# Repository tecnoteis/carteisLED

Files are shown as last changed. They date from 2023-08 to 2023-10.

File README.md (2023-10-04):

# Carteis LED 
Repositorio cos deseños dos carteis feitos con tiras LED
Neste repo subiremos a información para fabricar os carteis que deseñamos no IES de Teis desde decembro de 2022.

Cartel do IES de Teis 
O primeiro modelo foi construido para inaugurar as vacacións de nadal Abel's stile.
cartelIESTeis1
Consiste nunha serie de letras impresas en 3D con tapas de metacrilato cortadas coa cortadora láser e ancladas a unha base de DM tamén cortada coa láser. Cada letra ten, no interior, tiras LED WS2812B unidas en serie mediante cableado que vai dentro da base. A controladora é unha Arduino UNO R3, pero pode ser calquera que manexe a bilioteca de Adafruit para os Neopixel, que utilizamos para controlar os xogos de cores que fai o cartel.
As letras foron deseñadas en Onshape: https://cad.onshape.com/documents/4773bc60c2ff5bee8ad740b4/w/625422397d679016f6e905c3/e/1a73bd1ce32b01c9ed044d96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

Necesitas unha conta de Onshape para copiar nela os deseños e na documentación hai un vídeo titorial con instrucións para crear as letras que necesites.
A tira de LEDs conéctase segundo o esquema que podes ver no cartafol "EsquemasFritzing". Ten un sentido de conexión, podes cortar tantos tramos como necesites, pero hai un lado que é a entrada e outro a saida da alimentación e a programación, por dicilo dalgunha maneira. A listaxe de materiais está no ficheiro BOM.ods, no que podes acceder a ligazóns para mercar en eliexpress.

cableadoLetraE

Cada letra ten un burato para a entrada dos cables e outro para a saída, e as tiras LED están colocadas tendo en conta a entrada e saída.
A tapa das letras tamén está en Onshape, e poden ser cortadas en metacrilato traslúcido coa cortadora láser ou poden ser impresas en 3D en plástico branco ou traslúcido. Neste caso recomendamos cambiar o deseño das letras para que o encaixe sexa de 1 mm e non de 3 mm , que é o grosor do metacrilato. Con tapas de PLA de 1 mm ou menos, a luz dos LEDs queda ben.
No cartafol "Titoriais" tedes o titorial para modificar os deseños das letras.
Para a base utilizamos un deseño de caixas, con encaixes tipo dedo, obtido da web makercase.com. Utilizamos DM de 3mm e o tamaño necesario para soportar as letras.

baseCartel

Carteis con mensaxe

Como colaboración co grupo de Igualdade do IES de Teis elaboramos dous modelos de carteis, unha caixa de DM para o espazo de reunión do grupo e outro modelo con electrónica móbil, que servira para múltiples mensaxes. Nestes carteis utilizamos como material translúcido unha plancha obtida de reciclar un panel LED avariado, de 60x60 cm, que foi cambiado do teito do taller.
carteisAcesos inteirosAcesp

A caixa de DM creámola na web makercase.com e cortámola coa láser e as caixas de cartón son caixas de portátiles edixgal pintadas e cortadas coa láser.
A electrónica ten o mesmo esquema que o cartel do IES de Teis, pero está pegada a unha base rectángular, tal como podes ver na imaxe.
panelLED

A alimentación pode ser con baterías recargables 18650 ou cunha fonte de alimentación conectada á placa Arduino.
Nun dos carteis utilizamos un powerbank conectado como nos mClons: https://tecnoloxia.org/mclon/alimentacion/powerbank/

O programa que fai que a tira de LED faga distintos xogos de cores e intensidades é unha modificación do exemplo "RGBWstrandtest" incluido na biblioteca de Adafruit para as tiras de LED Neopixel. Podes descargar aquí a biblioteca para instalala no IDE de Arduino e o programa de exemplo, aínda que xa aparece despois de instalar a biblioteca. No programa só tes que modificar o pin no que está conectado o pin data da tira de LED e o número total de LED da tira. Despois podes xogar co brillo ou co que queiras.

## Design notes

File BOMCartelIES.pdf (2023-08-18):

CartelIESTeis

Páxina 1

Peza | Nº de pezas necesarias | Prezo agosto 2023 | Ligazón aliexpress
Arduino UNO R3 compatible | 1 | 4,47 € | Aliex (https://es.aliexpress.com/item/32272099710.html?curPageLogUid=CH7IBoWkon00)
Tira LED WS2812B 5m 60 IP30 | 1 | 11,03 € | Aliex (https://es.aliexpress.com/item/32877299440.html)
Fuente alimentación 5V 3A micro USB | 1 | 4,65 € | Aliex (https://es.aliexpress.com/item/32806358968.html?curPageLogUid=9muuapCcvmBS)
Condensador 1000uF 20 unidades | 1 | 0,29 € | Aliex (https://es.aliexpress.com/item/1005001496103526.html?curPageLogUid=xPTq4Nx9Ri04)
Resistencia 470Ω. 20 unidades | 1 | 0,69 € | Aliex (https://es.aliexpress.com/item/1005001931818502.html?curPageLogUid=t3cmH7ZhH533)
Porto micro USB a micro USB 30cm | 1 | 0,75 € | Aliex (https://es.aliexpress.com/item/4001084210384.html)
Carcasa powerbank | 1 | 1,32 € | Aliex (https://es.aliexpress.com/item/1005005057752217.html?curPageLogUid=ehSRrVEmZi6p)

Cartel con OLR

Peza | Nº de pezas
Arduino UNO R3 compatible | 1 | 4,47 €
Tira LED WS2812B 5m 60 IP30 | 1 | 11,03 €
Fuente alimentación 5V 3A micro USB | 1 | 4,65 €
Condensador 1000uF 20 unidades | 1 | 0,29 €
| 1 | 0,69 €
| 1 | 4,04 €
Porto micro USB a micro USB 30cm | 1 | 0,75 €
Amplificador con potenciómetro de 5V | 1 | 0,72 €
Tiras femia 8 pines 2,54mm 10 unidades | 1 | 0,49 €
Condensador 1uF. 100 unidades | 1 | 0,92 €

Prezo agosto
2023

Ligazón
aliexpress
Aliex (https://es.aliexpress.com/item/32272099710.html?curPageLogUid=CH7IBoWkon00)
Aliex (https://es.aliexpress.com/item/32877299440.html)
Aliex (https://es.aliexpress.com/item/32806358968.html?curPageLogUid=9muuapCcvmBS)
Aliex (https://es.aliexpress.com/item/1005001496103526.html?curPageLogUid=xPTq4Nx9Ri04)
Resistencia 470Ω. 20 unidades | Aliex (https://es.aliexpress.com/item/1005001931818502.html?curPageLogUid=t3cmH7ZhH533)
Altofalante 8Ω 2W. 5 unidades | Aliex (https://es.aliexpress.com/item/1005004737415991.html?curPageLogUid=Urzz0UNmV8cW)
| Aliex (https://es.aliexpress.com/item/4001084210384.html)
| Aliex (https://es.aliexpress.com/item/32452488898.html)
| Aliex (https://es.aliexpress.com/item/32677173846.html)
| Aliex (https://es.aliexpress.com/item/1005005222055000.html?curPageLogUid=zJ3RMINrEEkh)

CaixaArcade

Peza | Nº de pezas
Pantalla LCD 8” 4:3 HDMI 1024x768 | 1 | 41,00 €
Conector HDMI macho para cable plano (modelo A2) | 2 | 2,10 €
Cable HDMI plano sen conectores 15 cm | 1 | 2,10 €
Porto micro USB a micro USB 30cm | 1 | 0,75 €
Porto USB A femia a USB macho A 25 cm | 1 | 1,13 €
Kit Joystick | 1 | 16,99 €
Amplificador con potenciómetro de 5V | 1 | 0,72 €
Disipador calor Raspberry Pi 3 | 1 | 3,68 €
Fuente alimentación 5V 3A micro USB | 1 | 4,64 €
Tiras femia 8 pines 2,54mm 10 unidades | 1 | 0,49 €
Raspberry Pi 3 | 1 | ? | ?

Prezo agosto
2023

Ligazón
aliexpress
Aliex (https://es.aliexpress.com/item/4000928712378.html)
Aliex (https://es.aliexpress.com/item/4000014554460.html)
Aliex (https://es.aliexpress.com/item/4000014554460.html)
Aliex (https://es.aliexpress.com/item/4001084210384.html)
Aliex (https://es.aliexpress.com/item/10000349461127.html)
Aliex (https://es.aliexpress.com/item/1005002891375251.html)
Aliex (https://es.aliexpress.com/item/32452488898.html)
Aliex (https://es.aliexpress.com/item/1005002179849106.html?curPageLogUid=135oRgnrqkqs)
Aliex (https://es.aliexpress.com/item/32806358968.html?curPageLogUid=9muuapCcvmBS)
Aliex (https://es.aliexpress.com/item/32677173846.html)

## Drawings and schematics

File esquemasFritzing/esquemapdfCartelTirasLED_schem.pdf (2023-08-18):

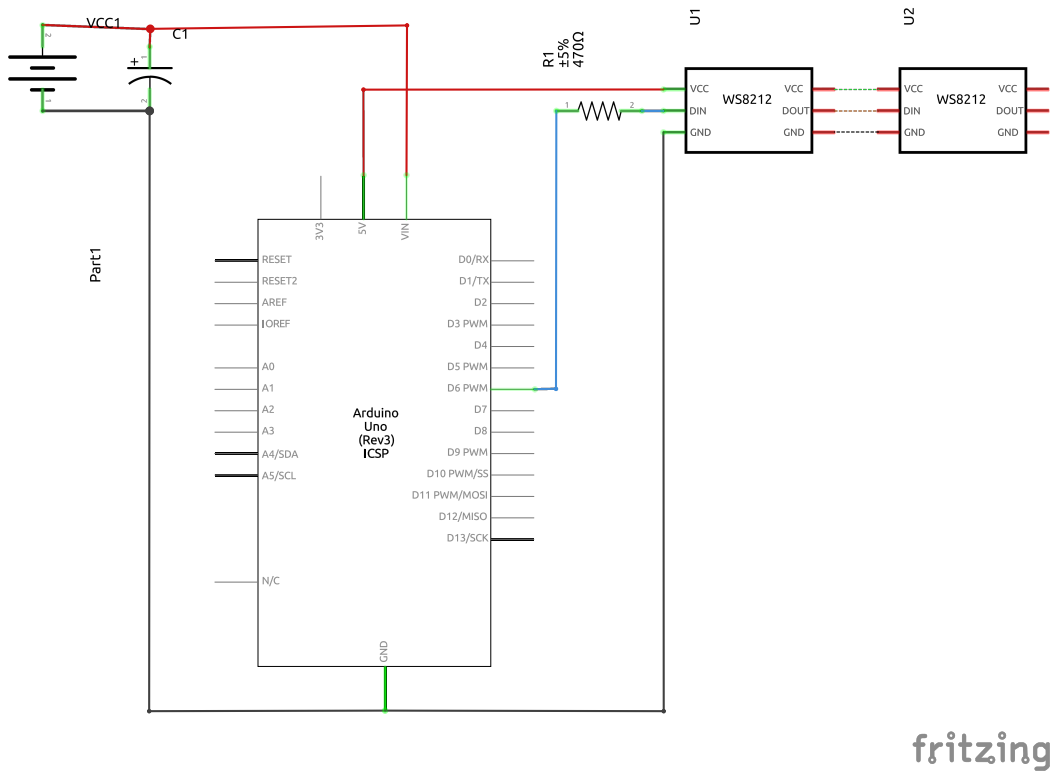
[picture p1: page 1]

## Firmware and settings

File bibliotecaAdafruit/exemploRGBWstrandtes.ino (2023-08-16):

// NeoPixel test program showing use of the WHITE channel for RGBW
// pixels only (won't look correct on regular RGB NeoPixel strips).

#include <Adafruit_NeoPixel.h>
#ifdef __AVR__
 #include <avr/power.h> // Required for 16 MHz Adafruit Trinket
#endif

// Which pin on the Arduino is connected to the NeoPixels?
// On a Trinket or Gemma we suggest changing this to 1:
#define LED_PIN     6

// How many NeoPixels are attached to the Arduino?
#define LED_COUNT  60

// NeoPixel brightness, 0 (min) to 255 (max)
#define BRIGHTNESS 50 // Set BRIGHTNESS to about 1/5 (max = 255)

// Declare our NeoPixel strip object:
Adafruit_NeoPixel strip(LED_COUNT, LED_PIN, NEO_GRBW + NEO_KHZ800);
// Argument 1 = Number of pixels in NeoPixel strip
// Argument 2 = Arduino pin number (most are valid)
// Argument 3 = Pixel type flags, add together as needed:
//   NEO_KHZ800  800 KHz bitstream (most NeoPixel products w/WS2812 LEDs)
//   NEO_KHZ400  400 KHz (classic 'v1' (not v2) FLORA pixels, WS2811 drivers)
//   NEO_GRB     Pixels are wired for GRB bitstream (most NeoPixel products)
//   NEO_RGB     Pixels are wired for RGB bitstream (v1 FLORA pixels, not v2)
//   NEO_RGBW    Pixels are wired for RGBW bitstream (NeoPixel RGBW products)

void setup() {
  // These lines are specifically to support the Adafruit Trinket 5V 16 MHz.
  // Any other board, you can remove this part (but no harm leaving it):
#if defined(__AVR_ATtiny85__) && (F_CPU == 16000000)
  clock_prescale_set(clock_div_1);
#endif
  // END of Trinket-specific code.

  strip.begin();           // INITIALIZE NeoPixel strip object (REQUIRED)
  strip.show();            // Turn OFF all pixels ASAP
  strip.setBrightness(BRIGHTNESS);
}

void loop() {
  // Fill along the length of the strip in various colors...
  colorWipe(strip.Color(255,   0,   0)     , 50); // Red
  colorWipe(strip.Color(  0, 255,   0)     , 50); // Green
  colorWipe(strip.Color(  0,   0, 255)     , 50); // Blue
  colorWipe(strip.Color(  0,   0,   0, 255), 50); // True white (not RGB white)

  whiteOverRainbow(75, 5);

  pulseWhite(5);

  rainbowFade2White(3, 3, 1);
}

// Fill strip pixels one after another with a color. Strip is NOT cleared
// first; anything there will be covered pixel by pixel. Pass in color
// (as a single 'packed' 32-bit value, which you can get by calling
// strip.Color(red, green, blue) as shown in the loop() function above),
// and a delay time (in milliseconds) between pixels.
void colorWipe(uint32_t color, int wait) {
  for(int i=0; i<strip.numPixels(); i++) { // For each pixel in strip...
    strip.setPixelColor(i, color);         //  Set pixel's color (in RAM)
    strip.show();                          //  Update strip to match
    delay(wait);                           //  Pause for a moment
  }
}

void whiteOverRainbow(int whiteSpeed, int whiteLength) {

  if(whiteLength >= strip.numPixels()) whiteLength = strip.numPixels() - 1;

  int      head          = whiteLength - 1;
  int      tail          = 0;
  int      loops         = 3;
  int      loopNum       = 0;
  uint32_t lastTime      = millis();
  uint32_t firstPixelHue = 0;

  for(;;) { // Repeat forever (or until a 'break' or 'return')
    for(int i=0; i<strip.numPixels(); i++) {  // For each pixel in strip...
      if(((i >= tail) && (i <= head)) ||      //  If between head & tail...
         ((tail > head) && ((i >= tail) || (i <= head)))) {
        strip.setPixelColor(i, strip.Color(0, 0, 0, 255)); // Set white
      } else {                                             // else set rainbow
        int pixelHue = firstPixelHue + (i * 65536L / strip.numPixels());
        strip.setPixelColor(i, strip.gamma32(strip.ColorHSV(pixelHue)));
      }
    }

    strip.show(); // Update strip with new contents
    // There's no delay here, it just runs full-tilt until the timer and
    // counter combination below runs out.

    firstPixelHue += 40; // Advance just a little along the color wheel

    if((millis() - lastTime) > whiteSpeed) { // Time to update head/tail?
      if(++head >= strip.numPixels()) {      // Advance head, wrap around
        head = 0;
        if(++loopNum >= loops) return;
      }
      if(++tail >= strip.numPixels()) {      // Advance tail, wrap around
        tail = 0;
      }
      lastTime = millis();                   // Save time of last movement
    }
  }
}

void pulseWhite(uint8_t wait) {
  for(int j=0; j<256; j++) { // Ramp up from 0 to 255
    // Fill entire strip with white at gamma-corrected brightness level 'j':
    strip.fill(strip.Color(0, 0, 0, strip.gamma8(j)));
    strip.show();
    delay(wait);
  }

  for(int j=255; j>=0; j--) { // Ramp down from 255 to 0
    strip.fill(strip.Color(0, 0, 0, strip.gamma8(j)));
    strip.show();
    delay(wait);
  }
}

void rainbowFade2White(int wait, int rainbowLoops, int whiteLoops) {
  int fadeVal=0, fadeMax=100;

  // Hue of first pixel runs 'rainbowLoops' complete loops through the color
  // wheel. Color wheel has a range of 65536 but it's OK if we roll over, so
  // just count from 0 to rainbowLoops*65536, using steps of 256 so we
  // advance around the wheel at a decent clip.
  for(uint32_t firstPixelHue = 0; firstPixelHue < rainbowLoops*65536;
    firstPixelHue += 256) {

    for(int i=0; i<strip.numPixels(); i++) { // For each pixel in strip...

      // Offset pixel hue by an amount to make one full revolution of the
      // color wheel (range of 65536) along the length of the strip
      // (strip.numPixels() steps):
      uint32_t pixelHue = firstPixelHue + (i * 65536L / strip.numPixels());

      // strip.ColorHSV() can take 1 or 3 arguments: a hue (0 to 65535) or
      // optionally add saturation and value (brightness) (each 0 to 255).
      // Here we're using just the three-argument variant, though the
      // second value (saturation) is a constant 255.
      strip.setPixelColor(i, strip.gamma32(strip.ColorHSV(pixelHue, 255,
        255 * fadeVal / fadeMax)));
    }

    strip.show();
    delay(wait);

    if(firstPixelHue < 65536) {                              // First loop,
      if(fadeVal < fadeMax) fadeVal++;                       // fade in
    } else if(firstPixelHue >= ((rainbowLoops-1) * 65536)) { // Last loop,
      if(fadeVal > 0) fadeVal--;                             // fade out
    } else {
      fadeVal = fadeMax; // Interim loop, make sure fade is at max
    }
  }

  for(int k=0; k<whiteLoops; k++) {
    for(int j=0; j<256; j++) { // Ramp up 0 to 255
      // Fill entire strip with white at gamma-corrected brightness level 'j':
      strip.fill(strip.Color(0, 0, 0, strip.gamma8(j)));
      strip.show();
    }
    delay(1000); // Pause 1 second
    for(int j=255; j>=0; j--) { // Ramp down 255 to 0
      strip.fill(strip.Color(0, 0, 0, strip.gamma8(j)));
      strip.show();
    }
  }

  delay(500); // Pause 1/2 second
}
